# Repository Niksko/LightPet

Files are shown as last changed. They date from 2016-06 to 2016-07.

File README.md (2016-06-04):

Light Pet Client
================

This repository contains code and related documentation for the Light Pet hardware.

## NodeMCU

The hardware platform is the NodeMCU obtained from [here](http://www.aliexpress.com/item/Update-Industry-4-0-New-esp8266-NodeMCU-v2-Lua-WIFI-networking-development-kit-board-based-on/32358722888.html).
The version I have appears to be the 2nd generation / v1.0 / V2 board ([comparison of NodeMCU boards](http://frightanic.com/iot/comparison-of-esp8266-nodemcu-development-boards))
and is pictured below along with a pinout.
My board appears to be the 'official' Amica version that complies with the NodeMCU spec, but with Aliexpress it's
always a bit difficult to tell.

![Image of NodeMCU v1.0]
(docs/images/nodemcuv2.jpg)

![NodeMCU v1.0 pinout]
(docs/images/NodeMCUPinout.jpg)

## Bill of materials

Quantity | Item | Notes
---------|------|------
1 | [NodeMCU v1.0](http://www.aliexpress.com/item/Update-Industry-4-0-New-esp8266-NodeMCU-v2-Lua-WIFI-networking-development-kit-board-based-on/32358722888.html) |
1 | [TSL257 light to voltage converter](http://www.aliexpress.com/item/Free-shipping-new-original-TSL257-TSL257-LF-red-ray-receiving-sensor/32598330231.html) | I chose this over regular photresistors because this seems to give a greater range of usable results.
1 | [KY-037 microphone module](http://www.aliexpress.com/item/5PCS-High-Sensitivity-Sound-Microphone-Sensor-Detection-Module-For-Arduino-AVR-PIC-KY-037/32569630843.html) | I may swap this out for something else in the future, or some other sort of sound sensor. This isn't quite as sensitive as I'd hoped for, and it's impossible to read a usable sound wave without an external DAC and possibly expanded storage to store the sound samples.
1 | [SHT21 I2C temperature and humdity sensor](http://www.aliexpress.com/item/1pc-Humidity-Sensor-with-I2C-Interface-Si7021-Arduino-Industrial-High-Precision/32562012725.html) |
1 | 4052 analog multiplexer | This is used to multiplex the TSL257 signal and the KY-037 signal into the NodeMCU's single input. I have the TI version (CD4052B) but NXP make an equivalent unit with the same pinout under the part number 74HCT4052.
  | Assorted resistors
  | Assorted capacitors
  | Assorted jumper cables for breadboarding

At the moment everything is constructed on a breadboard (pictured below), however at some point it would
be nice to make things more permanent with a home etched circuit board.

![Light pet on breadboard]
(docs/images/breadboard.jpg)

Below is a schematic of the circuit you need to get all of the sensors working properly. Also note that I have
included a [Fritzing](http://fritzing.org/home/) file for your convenience in the `docs` folder.
Datasheets for the parts that I used can be found in the `docs/datasheets` folder if more information on the reasons
for particular parts is needed.

Briefly:

* The SHT21 datasheet shows a sample circuit which includes the two resistors and the capacitor.
* We use a voltage divider across the TSL257 to just lower the output voltage a little so that it doesn't clip on the NodeMCU's analog input

![Light pet schematic]
(docs/images/schematic.png)

## Software

My NodeMCU board came with the Arduino firmware. If yours doesn't (I think some versions come with Lua based firmware)
then you'll need to flash the Arduino firmware to use the code I've provided.

My code makes use of a few libraries that you'll need to install using the library manager in the Arduino IDE. These
are:

* [A library for the SI7021 from Low Power Labs](https://github.com/LowPowerLab/SI7021)
* [The nanopb library for dealing with protobufs](https://github.com/nanopb/nanopb)
* The TaskScheduler library for making use of protothreading.

The first two libraries should be installed by downloading a zip of the master branch from the linked github pages
and then installing them in the Arduino IDE with Sketch->Include Library->Add .ZIP library. The TaskScheduler library
should be available via the Sketch->Include Library->Manage Libraries interface.

You'll also need to add the ESP8266 boards to your Arduino IDE by following [these](https://github.com/esp8266/Arduino)
instructions. This should also add the ESP8266 specific libraries we will be using.

Currently the code writes the protobuf encoded data to the Serial connection, but the next step will be to send
this to a location on the network via UDP.

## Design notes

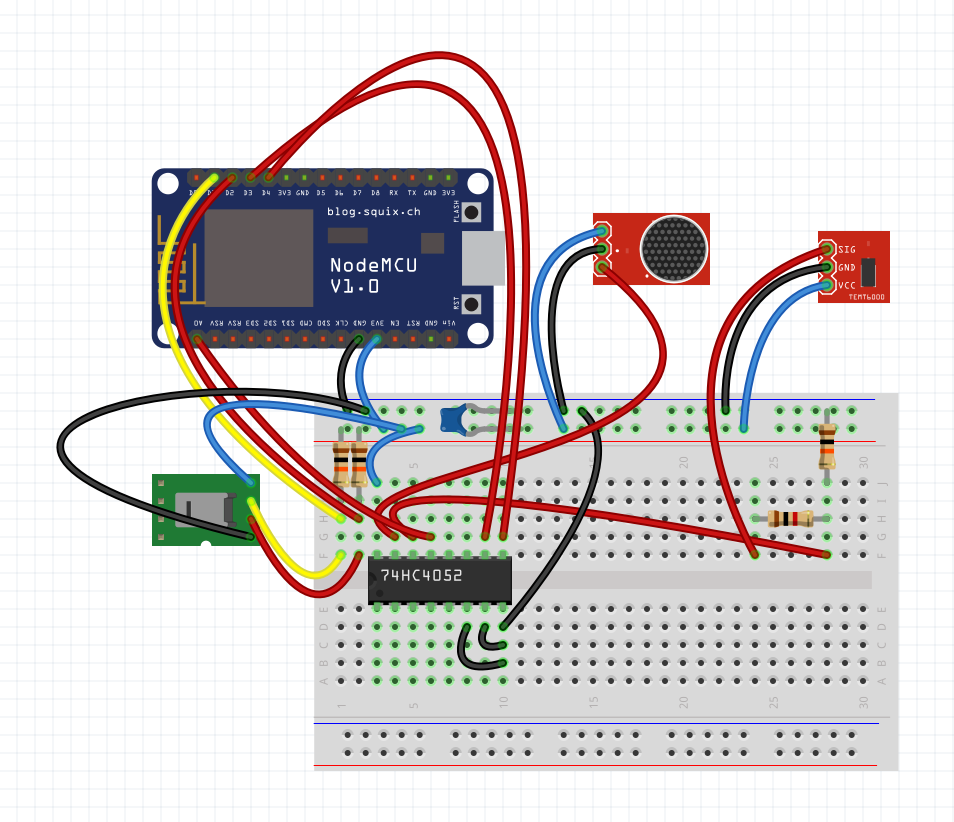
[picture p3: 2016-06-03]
docs/images/schematic.png

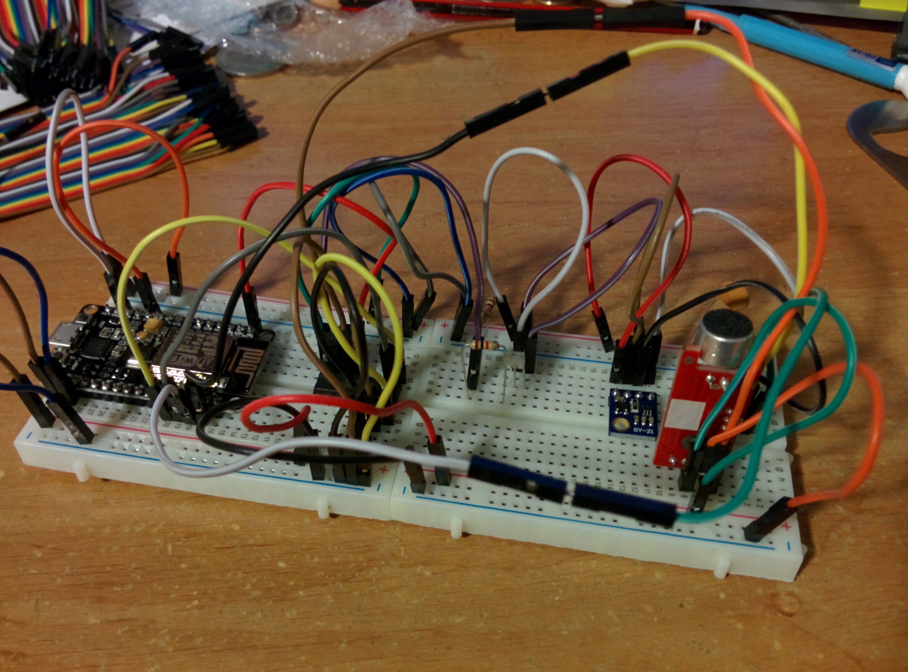
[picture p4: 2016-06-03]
docs/images/breadboard.jpg

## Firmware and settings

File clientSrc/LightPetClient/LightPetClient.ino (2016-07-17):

#include <pb_common.h>
#include <pb.h>
#include <pb_encode.h>
#include <pb_decode.h>
#include "sensorData.pb.h"
#include "configuration.h"

#include <TaskScheduler.h>
#include <Wire.h>
#include <SI7021.h>
#include <ESP8266WiFi.h>
#include <WiFiUdp.h>

// The following file should #define two values, WIFI_SSID and WIFI_PASSWORD, the ssid and pass for the network you
// want to connect to
#include "wifi.credentials.h"

// Relevant pin definitions. MUX pins are as per datasheet
#define MUX_A_PIN D3
#define MUX_B_PIN D4
#define SCL_PIN D1
#define SDA_PIN D2
#define ANALOG_PIN A0

// Just to avoid magic numbers, define the ms in a second
#define MS_PER_SECOND 1000

// Make a typdef to define an array with associated size. This will be used to encode packed arrays in protobufs
typedef struct _ArrayWithSize {
  uint32_t **array;
  size_t arraySize;
} ArrayWithSize;

// Variables used to store data values read from sensors
uint32_t microphoneData[MICROPHONE_SAMPLE_RATE / DATA_SEND_RATE + DATA_BUFFER_SIZE];
uint32_t lightData[LIGHT_SAMPLE_RATE / DATA_SEND_RATE + DATA_BUFFER_SIZE];
uint32_t temperatureData[TEMP_HUMIDITY_SAMPLE_RATE / DATA_SEND_RATE + DATA_BUFFER_SIZE];
uint32_t humidityData[TEMP_HUMIDITY_SAMPLE_RATE / DATA_SEND_RATE + DATA_BUFFER_SIZE];
si7021_env envData;

// Variables used to store the size of valid data in the sensor data arrays
size_t microphoneDataSize = 0;
size_t lightDataSize = 0;
size_t temperatureDataSize = 0;
size_t humidityDataSize = 0;

// Used to read from Si7021 sensor
SI7021 sensor;

// Variable used to hold data from protobuf encode
uint8_t outputBuffer[512];
size_t message_length;
bool message_status;
pb_ostream_t outputStream;
SensorData outputData;

// Function prototypes for task callback functions
void readMicCallback();
void readLightCallback();
void readTempHumidityCallback();
void sendDataPacketCallback();
void sendClientServiceMessageCallback();
void listenForUDPPacketCallback();
void NTPSyncCallback();

// function prototype for ntpUnixTime
uint64_t ntpUnixTime(WiFiUDP &udp);

// Task objects used for task scheduling
Task readMic(MS_PER_SECOND / MICROPHONE_SAMPLE_RATE, TASK_FOREVER, &readMicCallback);
Task readLight(MS_PER_SECOND / LIGHT_SAMPLE_RATE, TASK_FOREVER, &readLightCallback);
Task readTempHumidity(MS_PER_SECOND / TEMP_HUMIDITY_SAMPLE_RATE, TASK_FOREVER, &readTempHumidityCallback);
Task sendDataPacket(MS_PER_SECOND / DATA_SEND_RATE, TASK_FOREVER, &sendDataPacketCallback);
Task sendClientServiceMessage(MS_PER_SECOND * ADVERTISEMENT_RATE, TASK_FOREVER, &sendClientServiceMessageCallback);
Task listenForUDPPacket(MS_PER_SECOND / DATA_RECEIVE_RATE, TASK_FOREVER, &listenForUDPPacketCallback);
Task NTPSync(MS_PER_SECOND * NTP_SYNC_TIMEOUT, TASK_FOREVER, &NTPSyncCallback);

// Set up a scheduler to schedule all of these tasks
Scheduler taskRunner;

// An IPAddress to hold the computed broadcast IP
IPAddress broadcastIP;

// An IPAddress to hold the server that we will send our UDP packets to
IPAddress serverIP(0, 0, 0, 0);

// A UDP instance
WiFiUDP udp;

// Create a variable to hold the Unix time during setup, as well as a variable to hold the current millis when
// we got this time. This way we can compute current NTP time by comparison
uint64_t NTPSyncTime;
uint64_t NTPSyncMillis;

// Set up the server magic string in a constant string variable
const char serverMagicString[] = SERVER_SERVICE_MESSAGE;

void setup() {
  // Set up serial
  Serial.begin(38400);

  // Set mux pins to output mode
  pinMode(MUX_A_PIN, OUTPUT);
  pinMode(MUX_B_PIN, OUTPUT);

  // Start the I2C connection with the si7021
  sensor.begin(SDA_PIN, SCL_PIN);

  // Connect to the wifi
  Serial.print("Connecting to:");
  Serial.println(WIFI_SSID);

  WiFi.begin(WIFI_SSID, WIFI_PASSWORD);
  
  // Wait until the wifi is connected
  while (WiFi.status() != WL_CONNECTED) {
    delay(500);
    Serial.print(".");
  }

  // Compute the broadcast IP
  broadcastIP = ~WiFi.subnetMask() | WiFi.gatewayIP();

  // Start up the UDP service
  udp.begin(UDP_PORT);

  // Add all the tasks to the runner and enable them
  taskRunner.addTask(readMic);
  taskRunner.addTask(readLight);
  taskRunner.addTask(readTempHumidity);
  taskRunner.addTask(sendDataPacket);
  taskRunner.addTask(sendClientServiceMessage);
  taskRunner.addTask(listenForUDPPacket);
  taskRunner.addTask(NTPSync);
  NTPSync.enable();
  readMic.enable();
  readLight.enable();
  readTempHumidity.enable();
  sendDataPacket.enable();
  sendClientServiceMessage.enable();
  listenForUDPPacket.enable();
}

// Helper function that configures the input select lines of the MUX so that the mic is feeding data to A0
void select_microphone() {
  digitalWrite(MUX_A_PIN, HIGH);
  digitalWrite(MUX_B_PIN, LOW);
}

// Helper function that configures the input select lines of the MUX so that the light sensor is feeding data to A0
void select_light() {
  digitalWrite(MUX_A_PIN, LOW);
  digitalWrite(MUX_B_PIN, HIGH);
}

void readMicCallback() {
  select_microphone();
  microphoneData[microphoneDataSize] = analogRead(ANALOG_PIN);
  microphoneDataSize = microphoneDataSize + 1;
}

void readLightCallback() {
  select_light();
  lightData[lightDataSize] = analogRead(ANALOG_PIN);
  lightDataSize = lightDataSize + 1;
}

void readTempHumidityCallback() {
  envData = sensor.getHumidityAndTemperature();
  temperatureData[temperatureDataSize] = envData.celsiusHundredths;
  humidityData[humidityDataSize] = envData.humidityBasisPoints;
  temperatureDataSize = temperatureDataSize + 1;
  humidityDataSize = humidityDataSize + 1;
}

// Send the special UDP packaet advertising this device as a light pet client device
void sendClientServiceMessageCallback() {
  udp.beginPacket(broadcastIP, UDP_PORT);
  udp.write(CLIENT_SERVICE_MESSAGE);
  udp.endPacket();
}

void listenForUDPPacketCallback() {
  int packetSize = udp.parsePacket();
  if (packetSize) {
    // Read the packet into a packetBuffer
    char packetBuffer[UDP_MAX_SIZE];
    int readLength = udp.read(packetBuffer, UDP_MAX_SIZE);
    // Null terminate the packet data so that we can do string comparison below
    packetBuffer[readLength] = 0;

    // Depending on the contents, take different action
    if (strcmp(packetBuffer, serverMagicString) == 0) {
      serverIP = udp.remoteIP();
    }
    else {
      // Only accept packets from the IP matching our light pet server
      if (serverIP == udp.remoteIP()) {
        // The message is a data message. For the moment just print it, but eventually this will
        // be where we decode the protobuf format and update state based on the data
        for (int i = 0; i < readLength; i++) {
          Serial.print(packetBuffer[i]);
          Serial.print(" ");
        }
        Serial.print("\n");
      }
    }
  }
}

void NTPSyncCallback() {
  // Get the time from an NTP server and set NTP sync values appropriately
  static WiFiUDP timeUDP;
  NTPSyncTime = ntpUnixTime(timeUDP);
  NTPSyncMillis = (uint64_t) millis();
}

void sendDataPacketCallback() {
  // Zero our sensor data object
  outputData = SensorData_init_zero;
  // Set some fields in the output data
  // Compute the current NTP time with currentmillis - syncmillis + synctime * 1000 (since synctime is in seconds)
  // FIXME: This will have issues if millis overflows back to 0. This should probably trigger an NTP sync. Set this
  // up once we have a ntp sync task
  outputData.timestamp = ((uint64_t) millis()) - NTPSyncMillis + (NTPSyncTime * 1000);
  outputData.has_timestamp = true;

  outputData.temperatureSampleRate = TEMP_HUMIDITY_SAMPLE_RATE;
  outputData.has_temperatureSampleRate = true;

  outputData.humiditySampleRate = TEMP_HUMIDITY_SAMPLE_RATE;
  outputData.has_humiditySampleRate = true;

  outputData.audioSampleRate = MICROPHONE_SAMPLE_RATE;
  outputData.has_audioSampleRate = true;

  outputData.lightSampleRate = LIGHT_SAMPLE_RATE;
  outputData.has_lightSampleRate = true;

  outputData.chipID = ESP.getChipId();
  outputData.has_chipID = true;

  // Setup the callback functions for the variable length packed data segments
  outputData.temperatureData.funcs.encode = &encodePackedArray;
  outputData.humidityData.funcs.encode = &encodePackedArray;
  outputData.audioData.funcs.encode = &encodePackedArray;
  outputData.lightData.funcs.encode = &encodePackedArray;

  // Setup the arguments for these functions
  ArrayWithSize arg[4];
  arg[0].array = (uint32_t**)&temperatureData;
  arg[0].arraySize = temperatureDataSize;
  outputData.temperatureData.arg = &(arg[0]);

  arg[1].array = (uint32_t**)&humidityData;
  arg[1].arraySize = humidityDataSize;
  outputData.humidityData.arg = &(arg[1]);

  arg[2].array = (uint32_t**)&lightData;
  arg[2].arraySize = lightDataSize;
  outputData.lightData.arg = &(arg[2]);
 
  arg[3].array = (uint32_t**)&microphoneData;
  arg[3].arraySize = microphoneDataSize;
  outputData.audioData.arg = &(arg[3]);

  // Setup the output stream for our protobuf encode to output to our outputBuffer
  outputStream = pb_ostream_from_buffer(outputBuffer, sizeof(outputBuffer));

  // Encode the data to the stream
  message_status = pb_encode(&outputStream, SensorData_fields, &outputData);
  message_length = outputStream.bytes_written;

  // Depending on the status, write a different thing to the serial monitor
  if (!message_status) {
    Serial.println("Encoding failed");
    Serial.println(PB_GET_ERROR(&outputStream));
  }
  else {
    // If we have a real server, not just the default 0.0.0.0 IP
    if (serverIP != IPAddress(0, 0, 0, 0)) {
      // Send the encoded data from the output buffer
      udp.beginPacket(serverIP, UDP_PORT);
      udp.write(outputBuffer, message_length);
      udp.endPacket();
    }
    else {
      // Just print to serial
      for (int i = 0; i < message_length; i++) {
        Serial.print(outputBuffer[i]);
        Serial.print(" ");
      }
      Serial.print("\n");
    }
  }

  // Reset the values that we use to track the size of our data arrays to zero
  temperatureDataSize = 0;
  humidityDataSize = 0;
  lightDataSize = 0;
  microphoneDataSize = 0;
}

bool encodePackedArray(pb_ostream_t *stream, const pb_field_t *field, void * const *arg) {
  // First, set up a substream that we will use to figure out the length of our data
  pb_ostream_t dummySubstream = PB_OSTREAM_SIZING;
  size_t dataLength;

  ArrayWithSize *localArg = (ArrayWithSize*) *arg;

  // Write all of the data from the temperature data array to the dummy substream, then check the bytes written
  size_t arraySize = localArg->arraySize;
  uint32_t **localValues = localArg->array;
  for (int i = 0; i < arraySize; i++) {
    pb_encode_varint(&dummySubstream, (uint64_t) localValues[i]);
  }

  // Get the bytes written
  dataLength = dummySubstream.bytes_written;

  // Now we can actually do the encoding on the real stream
  // First encode the tag and field type. Since this is a packed array, we use the PB_WT_STRING type to denote that
  // it is length delimited
  if (!pb_encode_tag(stream, PB_WT_STRING, field->tag)) {
    return false;
  }

  // Next encode the data length we just found
  if (!pb_encode_varint(stream, (uint64_t) dataLength)) {
    return false;
  }

  // Finally encode the data as varints
  for (int i = 0; i < arraySize; i++) {
    if (! pb_encode_varint(stream, (uint64_t) localValues[i])) {
      return false;
    }
  }

  return true;
}

void loop() {
  taskRunner.execute();
}

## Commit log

2016-06-03 Initial commit
    This initial commit contains schematics, datasheets, images and some
    working code for the light pet project
    [LightPetSchematic.fzz]
2016-06-04 Update README with ESP8266 Arduino IDE setup
2016-06-04 Add Wifi connection and service advertisement
    This adds connection to a wifi network, as well as advertisement of the
    light pet client service via UDP multicast.
    The wifi credentials for the network are loaded via the
    wifi.credentials.h file, where you define WIFI_SSID and WIFI_PASSWORD.
    I have added this file to the gitignore to avoid leaking sensitive ssid
    and password information.
    [LightPetClient.ino]
2016-06-04 Add reaction to server advertisement
    This adds preliminary handling of the server advertisement message.
    At the moment we just look for incoming UDP packets on the right port.
    If they have the special server magic string, we then set what will
    become our target IP for data packets to the IP that the message came
    from. If they don't but they're on the correct port, we just print the
    data we got from them for the moment.
    [LightPetClient.ino]
2016-06-04 Update schematic slightly
    [LightPetSchematic.fzz]
2016-06-04 Add writing data from sensors to UDP
2016-06-05 Use strcmp instead of whatever I was doing before
    This properly detects incoming server advertisement messages by using
    strcmp to compare the known string to the incoming udp string. Whatever
    I was doing before didn't work.
    [LightPetClient.ino]
2016-06-05 Remove remote UDP port check
    We don't really care what port the advertisement comes from. We know
    that the destination port is correct because that's the only port we're
    listening on.
    [LightPetClient.ino]
2016-06-05 Sends the unix time based on NTP in protobuf
    We now send the current unix time in the encoded protobuf message. The
    NTP time is grabbed at setup (in the future this will be grabbed at regular
    intervals) and we compute the difference between the millis when we
    grabbed the time and the current millis, then add this to the NTP datum
    to get the current unix time.
2016-06-13 Add ArduinoJson to dependencies
2016-06-16 Revert "Add ArduinoJson to dependencies"
    This reverts commit 768e1e8c13397a5b3c83665e3375f1950faee7dd.
    Since we'll be compiling the code to send to the arduino, it's not much
    good having config that we'll need to parse at runtime.
    Instead I'm going to have a script that spits out a header file that
    will contain the definitions of the variables from the config file.
2016-06-16 Add a python script to write out config headers
    This script takes a configuration file called configuration.json and
    writes out a file called configuration.h which contains the relevant
    configuration values #defined
    This will allow us to single source our configuration values between
    both the arduino code and the server code
2016-06-16 Add Makefile and reference configuration.h
    This adds a Makefile which currently just spits out the configuration
    file. Our main client code file now includes the configuration file
2016-06-28 Add makefile generation of protobuf files
    This adds the generation of protobuf files for the Arduino client code
    and the Python server code to the makefile. As such we move the .proto
    file to the common folder.
    We also add gitignore filters for these generated files
2016-06-28 Add minimum working server code to dump data
    This adds minimum working server code that parses config from the
    common json config file, uses the generated protobuf bindings to grab
    data into a probtobuf container and then prints the data from this
    object to the console.
2016-06-29 Create wrapper around protobuf for sensor data
    This creates and uses a new SensorData class which serves as a handy
    wrapper around the protobuf class that is auto-generated
2016-06-29 Send timestamp as ms since unix epoch
    This sends the timestamp over the wire in units of milliseconds, which
    in theory allows us greater accuracy.
2016-06-29 Add periodic NTP sync and fix timestamp format
    This turns the NTP sync into a task that is run by our scheduler. At
    the moment we resync with NTP time every hour. We'll see if this is
    enough to prevent clock drift once we actually start logging data.
    This also fixes what we're sending over the wire as our timestamp.
    We're now correctly sending unix time in ms, which is then converted to
    seconds on the server end for conversion to a datetime object.
    Something was going wrong here, and I suspect it might have been 32bit
    integer overflow, hence why all of the relevant variables related to
    the NTP time calculations are now unit64_t or cast to it before
    calculation.
    [LightPetClient.ino]
2016-06-29 Add repr and asDict methods
    This moves the code from the repr function to the __str__ function.
    This frees the repr function to print out a string of a dict of the
    object, and we introduce an asDict method which will be used later to
    feed jsonifying objects
2016-06-30 Convert protobuf types to lists in properties
    The internal protobuf stores data in weird objects. This converts these
    to lists for the audio and light data. We were already doing this
    implicitly using the list comprehension used to scale the temperature
    and humidity.
    This is required so that we can convert the object's data to JSON for
    logging.
2016-06-30 Add logging of data and status
    This adds logging of information such as advertisements and logging of
    data to a file in json format.
    In order to separate the data from the information about advertisments,
    we set an attribute on the data LogRecords that indicates that they are
    data (record.data=True) and then filter these at the file handler that
    logs this data.
2016-07-16 Make general packet array encoder function
    Instead of having a separate function to encode packed arrays for each
    different array, we now use a single function and pass the array using
    the args property.
2016-07-17 Change parameter values
    This changes some of the polling rates of the sensors
